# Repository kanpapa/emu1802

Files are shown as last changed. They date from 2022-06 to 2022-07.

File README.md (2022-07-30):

# emu1802
The computer with only COSMAC CDP1802 and PIC18F47Q43/PIC18F27Q43  
developed by Kazuhiro Ouchi

The purpose of this experiment is to see if it is possible to make a real COSMAC work with fewer components, at a lower cost, and more compactly.

The EMU1802 is replacement the CPU of the EMUZ80 with a COSMAC.  
The EMU1802-mini is replacement the PIC of the EMU1802 with a PIC18F27Q43.  

## Repository Contents
- [emu1802.X](/emu1802.X/) - PIC18F47Q43 ROM RAM and UART emulation firmware for EMU1802
- [emu1802mini.X](/emu1802mini.X/) - PIC18F27Q43 ROM RAM and UART emulation firmware for EMU1802-mini
- [production](/production/) - Firmware hex files for EMU1802-mini
- [idiotmon](/idiotmon/) - IDIOT/4 monitor and sample programs
- [kicad/emu1802_sch.pdf](/kicad/emu1802_sch.pdf) - schematic of EMU1802
- [kicad/emu1802_mini_sch.pdf](/kicad/emu1802_mini_sch.pdf) - schematic of EMU1802-mini
- [kicad/emu1802_mini_bom.md](/kicad/emu1802_mini_bom.md) - BOM of EMU1802-mini
- [test_programs](/test_programs/) - Test programs for EMU1802 hardware
- [tools/bin2hexsrc.py](/tools/bin2hexsrc.py) - A tool to convert binaries to HEX
- [EMU1802mini_Setup_ja.md](/EMU1802mini_Setup_ja.md) - Setup manual for EMU1802mini (Japanese)
- [README.md](/README.md) - This manual

## Development tools
- [Microchip MPLAB IDE v6.00](https://www.microchip.com/en-us/tools-resources/develop/mplab-x-ide)
- [Microchip MPLAB SNAP](https://www.microchip.com/en-us/development-tool/PG164100)
- [SB-Assembler 3](https://www.sbprojects.net/sbasm/)
- Python3

## Blog
You can also refer to my blog. (in Japanese)  
https://kanpapa.com/cosmac/blog/emu1802/

## Pictures

The EMU1802-mini  
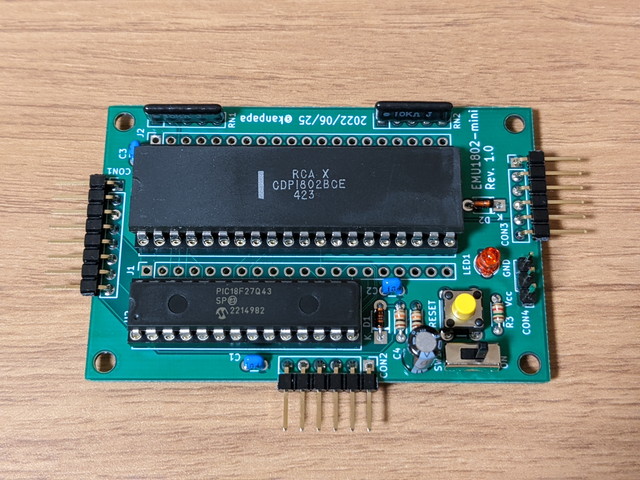
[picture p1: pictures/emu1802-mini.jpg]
EMU1802-mini


Testing of the EMU1802-mini  
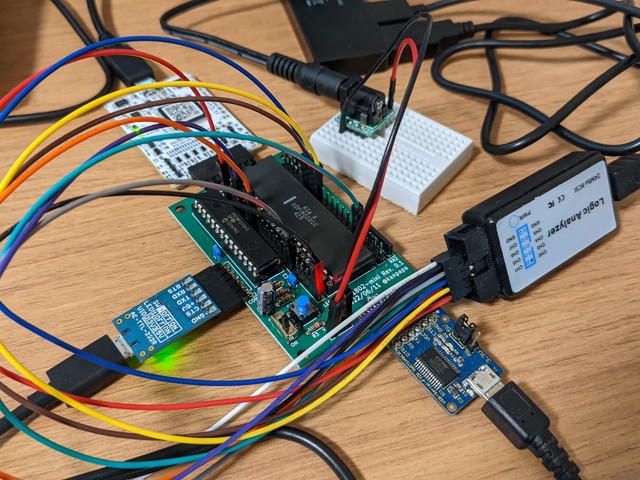
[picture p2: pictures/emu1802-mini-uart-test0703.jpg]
Testing of EMU1802-mini


The idiot monitor is working on the EMU1802-mini  
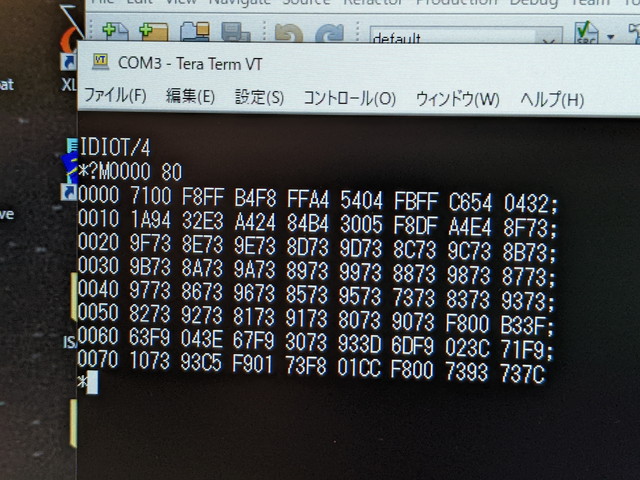
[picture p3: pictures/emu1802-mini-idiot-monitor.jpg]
The idiot monitor is working on emu1802-mini


Prototype of The EMU1802  
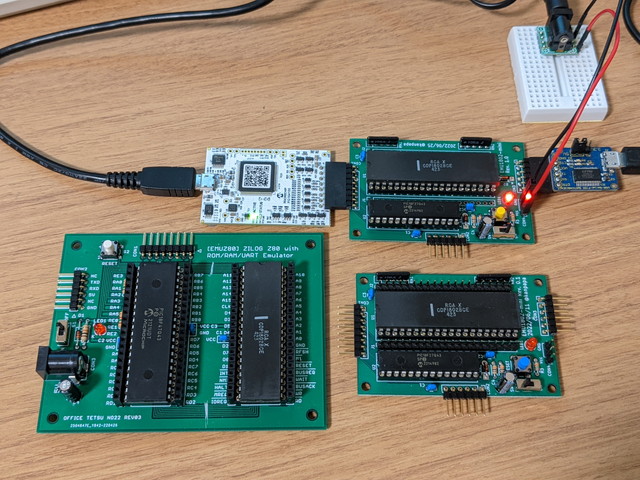
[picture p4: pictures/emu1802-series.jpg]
Prototype of The EMU1802


## License Information
References to any products, programs or services do not imply that they will be available in all countries in which their respective owner operates.  

Company, product, or services names may be trademarks or services marks of others.  

All libraries used in this code are copyright their respective authors.  

This project is based on the EMUZ80 hardware and software developed by Tetsuya Suzuki.

EMUZ80 - The computer with only Z80 and PIC18F47Q43  
  Written by Tetsuya Suzuki  
  https://github.com/vintagechips/emuz80  

The firmware includes the IDIOT monitor.  

IDIOT/4 MONITOR FOR THE 1802  
  WRITTEN: 6/23/82 BY LEE HART  
  COPYRIGHT 1982-85 BY TMSI  
  This program may be used for any noncommercial use free of charge.  
  fixes by Herb Johnson HRJ April 2010, Jan 2014  
  https://www.retrotechnology.com/memship/mship_idiot.html

Thanks to Gazelle for optimizing the firmware.  

  Modified by Gazelle  
  https://drive.google.com/drive/folders/14-OX5THzVz1BVxLPXheExVnpIBqS79NJ  
  1st release 2022-7-29

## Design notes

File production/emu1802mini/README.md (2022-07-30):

# production/emu1802mini
This is the firmware for the EMU1802-mini.  
It has been written to the PIC18F27Q43 with MPLAB X IPE v6.00 and MPLAB SNAP and confirmed to work.

## Repository Contents
There are two versions of the firmware.

- [v1_0](/production/emu1802mini/v1_0) : V1.0 - Original version of the IDIOT monitor, with ORG address changed to 0000H is included in the firmware. 300 bps is available.

- [v1_1](/production/emu1802mini/v1_1) : V1.1 - The IDIOT monitor that can use UART of PIC18F27Q43 is included in the firmware. 9600bps is available.

- [v2_1G](/production/emu1802mini/v2_1G) : V2.1G - Speedup to 1.79 MHz. Modified by Gazelle. 9600bps is available.

## License Information
This firmware includes the IDIOT monitor.
Please use it in compliance with the copyright and terms of use of the IDIOT Monitor.

IDIOT/4 MONITOR FOR THE 1802  
WRITTEN: 6/23/82 BY LEE HART  
COPYRIGHT 1982-85 BY TMSI  
This program may be used for any noncommercial use free of charge.  
fixes by Herb Johnson HRJ April 2010, Jan 2014  
https://www.retrotechnology.com/memship/mship_idiot.html

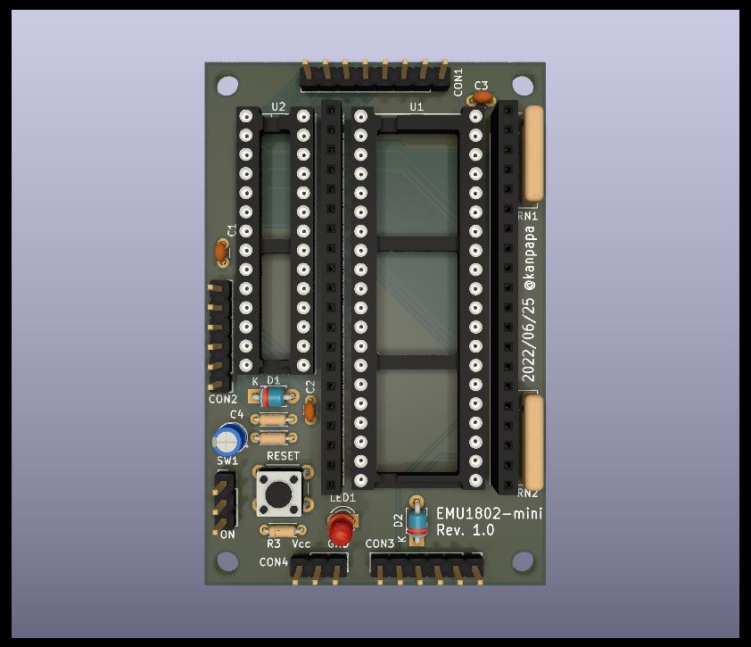
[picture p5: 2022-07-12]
pictures/emu1802_mini_front_3d.jpg

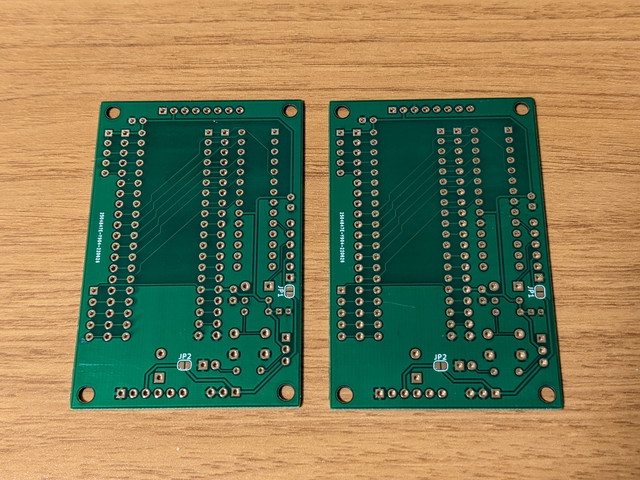
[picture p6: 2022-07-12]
pictures/emu1802-mini-pcb-back.jpg

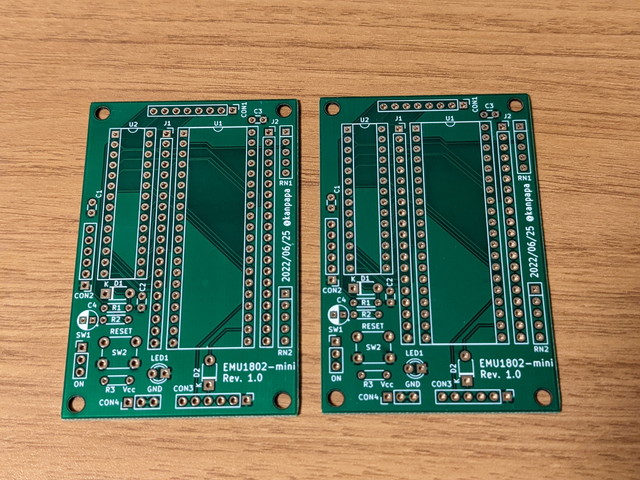
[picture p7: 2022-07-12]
pictures/emu1802-mini-pcb-front.jpg

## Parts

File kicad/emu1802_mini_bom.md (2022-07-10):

# EMU1802-mini Rev1.0 BOM
|Item|Qty|Reference(s)|Value|Description|Datasheet|
| --- | --- | --- | --- | --- | --- |
|1|3|C1, C2, C3|0.1u|Leaded MLCC 0.1uF50V 2.54mm|https://akizukidenshi.com/catalog/g/gP-00090/|
|2|1|C4|10uF|capacitor 10uF50V|https://akizukidenshi.com/catalog/g/gP-03116/|
|3|1|CON1|PICKIT/SNAP|2.54mm 8-Pin header strip straight(or right angle) single row|https://akizukidenshi.com/catalog/g/gC-00167/|
|4|1|CON2|UART|2.54mm 6-Pin header strip straight(or right angle) single row|https://akizukidenshi.com/catalog/g/gC-00167/|
|5|1|CON3|Software Serial|2.54mm 6-Pin header strip straight(or right angle) single row|https://akizukidenshi.com/catalog/g/gC-00167/|
|6|1|CON4|DC-IN|2.54mm 3-Pin header strip straight(or right angle) single row|https://akizukidenshi.com/catalog/g/gC-00167/|
|7|2|D1, D2|1N4148| Small Signal Diode 1N4148|https://akizukidenshi.com/catalog/g/gI-00941/|
|8|2|J1, J2|CPUA/B|2.54mm 20-Pin female header single row straight dip|https://akizukidenshi.com/catalog/g/gC-03077/|
|9|1|LED1|POWER LED|3mm LED|https://akizukidenshi.com/catalog/g/gI-11577/|
|10|2|R1, R2|10k|resistor 10k 1/6W|https://akizukidenshi.com/catalog/g/gR-16103/|
|11|1|R3|1.5k|resistor 1.5k 1/6W|https://akizukidenshi.com/catalog/g/gR-16152/|
|12|2|RN1,RN2|10K|SIP resistor 5-pin 4 x 10k|https://akizukidenshi.com/catalog/g/gR-11909/|
|13|1|SW1|POWER|slide switch SS-12D00G3|https://akizukidenshi.com/catalog/g/gP-15707/|
|14|1|SW2|RESET|tact switch TS-0606|https://akizukidenshi.com/catalog/g/gP-03649/|
|15|1|U1|CDP1802ACE|CDP1802ACE microprocessor|http://www.cosmacelf.com/publications/data-sheets/cdp1802.pdf|
|16|1|U2|PIC18F27Q43|Microchip PIC18F27Q43 microprocessor|https://akizukidenshi.com/catalog/g/gI-16593/|
|17|1|U1 socket||40-Pin IC socket 600mil |https://akizukidenshi.com/catalog/g/gP-00034/|
|18|1|U2 socket||28-Pin IC socket 300mil|https://akizukidenshi.com/catalog/g/gP-01339/|

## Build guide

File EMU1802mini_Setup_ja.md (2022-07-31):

# EMU1802-mini セットアップマニュアル

## EMU1802-miniとは

EMU1802-miniはCOSMAC CDP1802 CPUとPIC18F27Q43だけで動作するシングルボードコンピュータです。
PIC18F27Q43とPICに書き込むファームウェアで周辺デバイスであるROM, RAM, UARTの機能を実現しています。
Tetsuya Suzuki氏が開発した[EMUZ80](https://vintagechips.wordpress.com/2022/03/05/emuz80_reference/)を参考にして製作しています。  
COSMAC CPUについては[COSMAC研究会](https://kanpapa.com/cosmac/cosmac-cpu.html)のサイトをご覧ください。
これまでの経緯をまとめた[EMU1802アーカイブ](https://kanpapa.com/cosmac/blog/emu1802/)もあります。

EMU1802-miniの完成写真  
EMU1802-mini

## ハードウェアの製作

1. [回路図](/kicad/emu1802_mini_sch.pdf)と[BOM](/kicad/emu1802_mini_bom.md)を参考にしてパーツを入手してください。
1. [EMU1802-mini専用プリント基板](https://store.shopping.yahoo.co.jp/orangepicoshop/pico-A-057.html)があればパーツを基板に実装してハンダ付けします。基板がない場合はブレッドボードを使って配線しても良いでしょう。

- [EMU1802-mini専用プリント基板](https://store.shopping.yahoo.co.jp/orangepicoshop/pico-A-057.html)について

  - [オレンジピコショップ](https://store.shopping.yahoo.co.jp/orangepicoshop/)さんで購入できます。
  - EMU1802-mini専用基板を使用する際の注意事項
    - 基板には最低限の情報しかシルク印刷されていません。作業開始前に回路図を確認することをお勧めします。
    - CON4は電源入力です。１番ピンがVccです。２番ピンと３番ピンはGNDです。誤ってショートしないように注意してください。
    - CON2, CON3はUSBシリアルを接続するコネクタです。１番ピンがGNDになります。
    - USBシリアルから電源を供給する場合は裏面のJP1またはJP2を半田でショートしてください。
    - 省スペースのために1/6W抵抗を使用していますが、1/4W抵抗の場合はリード線を曲げて縦に取り付けてください。

## 開発環境の準備

- [Microchip MPLAB X IDE v6.00](https://www.microchip.com/en-us/tools-resources/develop/mplab-x-ide)が必要です。  
- ファームウェアの書き込みには[Microchip MPLAB SNAP](https://akizukidenshi.com/catalog/g/gM-13854)を使用します。
- ファームウェアのROM領域を変更する場合は[SB-Assembler 3](https://www.sbprojects.net/sbasm/)を使用します。このアセンブラはPython3で書かれているため、LinuxやMacやWindowsでPython3が動けば動作します。私の場合はWSL2環境にインストールしています。  

## ファームウェアのビルドと書き込み手順

EMU1802-miniはCOSMACのプログラムをPICのファームウェアに組み込んで使います。好きなプログラムを動かすためにはファームウェアのビルドは必須です。

1. [emu1802mini.X](/emu1802.X)を適当な場所に展開します。
1. [Microchip MPLAB X IDE v6.00](https://www.microchip.com/en-us/tools-resources/develop/mplab-x-ide)を起動します。
1. プロジェクトを開くで展開したemu1802mini.Xフォルダを指定して開きます。
1. MPLAB IDEでビルドを行いコンパイルができることを確認します。
1. EMU1802-miniのCON1にMPLAB SNAPを接続し、PCのUSBに接続します。
1. EMU1802-miniの電源を投入します。
1. MPLAB IDEでターゲットのPICに書き込みを行います。

## ビルド済みファームウェアの書き込み手順

[production](/production)にIDIOTモニタが含まれたビルド済のファームウェアのHEXファイルがありますので、これを利用することもできます。

1. 使用したいファームウェアをダウンロードしてください。詳しくは[README.md](/production/emu1802mini/README.md)を参照してください。
1. EMU1802-miniのCON1にMPLAB SNAPを接続し、PCのUSBに接続します。
1. EMU1802-miniの電源を投入します。
1. MPLAB IPEを起動します。
1. Device and Tool Selectionで、DeviceでPIC18F27Q43を選択し、ToolはSNAPを選択してください。
1. Hex FileのBrowseボタンを押して、ダウンロードしたファームウェアのHEXファイルを指定してください。
1. Erase→Blank Check→Program→Verifyを順に実行し、ターゲットのPICに書き込みます。

## EMU1802-miniの動作確認

ファームウェアV1.0の場合

1. USBシリアルをCON3（COSMACのQ/EF3）に接続します。
1. USBシリアルにPCを接続し、ターミナルプログラム(TeraTermなど）で300bps、スタート1ビット、データ長7ビット、パリティMark、ストップ1ビットに設定します。
1. EMU1802-miniの電源を投入します。
1. Enterキーを押すと、「IDIOT/4」起動メッセージとプロンプトの「*」が表示されます。

ファームウェアV1.1/V2.1Gの場合

1. USBシリアルをCON2（PICのUART）に接続します。
1. USBシリアルにPCを接続し、ターミナルプログラム(TeraTermなど）で9600bps、スタート1ビット、データ長8ビット、パリティ無し、ストップ1ビットに設定します。
1. EMU1802-miniの電源を投入します。
1. 「IDIOT/4」起動メッセージとプロンプトの「*」が表示されます。

## IDIOTモニタの使い方

### 基本的なコマンド

指定する値は16進数です。

| コマンド | 機能 |
----|----
|?Maaaa xx|アドレスaaaaからxxバイト分のメモリをダンプします |
|!Maaaa dd..dd;|アドレスaaaaから、ddの内容を書き込みます。<br>セミコロンをつけると次の行の内容も継続して書き込まれます。<br>これにより?Mコマンドでダンプした内容をキャプチャしておけば、キャプチャした内容をそのまま復元できます。|
|$Paaaa|割り込みを有効にして、PレジスタとXレジスタを0に設定した状態で、aaaaアドレスからのプログラムを実行します。|
|?R|最後の割り込み後に保存されたCPUのレジスタの値を表示します。|
|$Rxp|8FB8-8FDFのRAM領域の情報をCPUレジスタに設定します。<br>その後コマンドパラメタのxをXレジスタに、pをPレジスタに設定してプログラムの実行を行います。<br>つまり、Pレジスタで指定されたレジスタの内容が実行開始アドレスとなります。|

?Rコマンドの表示例

```
*?R
8FB8 00B2 0000 0000 0000;
8FC0 8000 00BB 8FE2 014E 0202 0224 FA7B 6BAD;
8FD0 002C BFFF 8004 5D6D 00EF 0000 0201 8080
```

レジスタとの対応は以下の通りです。

```
8FB8 ID T  DF D  IE Q  EF1234
8FC0 R0 R1 R2 R3 R4 R5 R6 R7
8FD0 R8 R9 RA RB RC RD RE RF
```

このレジスタの内容を使って$Rコマンドでレジスタの状態を設定したあとに実行することができます。

### コマンドの使用例

エコーバックをするプログラムを書き込んで実行した操作例です。  
ターミナルからテキストをアップロードする時は適切な送信遅延を入れてください。（後述の制限事項の項目を参照）

```
IDIOT/4
*!M8000 F880B4B5F817A4F80BA5D5F801B3F83EA3D354F89CA3D3003007
*?M8000 20
8000 F880 B4B5 F817 A4F8 0BA5 D5F8 01B3 F83E;
8010 A3D3 54F8 9CA3 D300 3007 0000 0000 0000
*$P8000
```

他にも有用なコマンドがあるかもしれません。詳細はソースファイルまたはIDIOTモニタのサイトを参照してください。  

- [COSMAC 1802 "IDIOT" monitor Software](https://www.retrotechnology.com/memship/mship_idiot.html)

## ファームウェアのカスタマイズ方法

### メモリマップの変更

main.cの以下の部分で設定できます。現在はROMエリアは$0000-$03FF、RAMエリアは$8000-8FFFとしています。ROMエリアは16Kbyte（$0000～$3FFF）まで設定できます。

```
#define ROM_SIZE 0x0400 // ROM size 1k bytes
#define RAM_SIZE 0x1000 // RAM size 4k bytes
#define RAM_TOP 0x8000 // RAM start address
```

### CPUクロックの変更

main.cの以下の部分の値を変更します。V2.1Gでは1.79MHzになっています。これ以上速くするとタイミングが合わなくなり動かなくなります。

```
#define Z80_CLK   1790000UL // CDP1802 clock frequency(2MHz)
```

### ROM領域の変更

ファームウェアのROM領域を変更する場合は[SB-Assemblers](https://www.sbprojects.net/sbasm/)でアセンブルしてバイナリファイルを生成したあとに、ファームウェアのソースファイルに組み込むためのHEXデータに変換します。  
[SB-Assemblers](https://www.sbprojects.net/sbasm/)のインストールと使用方法は公式サイトでご確認ください。  
インストールがうまくできていれば、以下のようにソースファイル名を指定するだけでカレントディレクトリにバイナリファイルとリストファイルができます。  

```
sbasm idiot_0000.asm
```

生成されたバイナリファイルを16進データ形式に変換するPythonプログラム [tools/bin2hexsrc.py](tools/bin2hexsrc.py) を用意していますので、これを使うとソースに組み込むデータを簡単に作成できます。  
使い方は以下の通りです。

```
python3 bin2hexsrc.py idiot_0000.bin > idiot_0000.hexsrc
```

生成された16進データを以下のrom配列の部分に組み込んでください。  
組み込むデータがROM_SIZEを超えてしまう場合はメモリマップを調整してください。

```
const unsigned char rom[ROM_SIZE] = {
   :
}
```

## 制限事項

EMU1802-miniはCOSMAC CPUの周辺デバイスをPICに置き換えています。このため以下の制限事項があります。

- 通常のRAMにくらべてPICからの読み込みは遅く、CPUクロックに上限があります。現在は1.79MHzが上限です。
- RESETを押すとRAM領域が初期化されます。通常のRAMですと電源が入っていればメモリの状態が保持されますが、PICがリセットされるのでRAMエリアは初期化されます。このため後述するIDIOTモニタの割り込みを活用してください。
- CPUの処理速度がついていけず、ターミナルからの入力で文字を取りこぼす場合があります。特にテキストをアップロードする時は適切な送信遅延を入れてください。目安として20ミリ秒/字、500ミリ秒/行程度は必要です。

## EMU1802-miniでのCOSMAC CPUの楽しみ方

### BASICを動かす方法

Lee A. Hart.さんの[The 1802 Membership Card](http://www.sunrise-ev.com/1802.htm)用のMCBASIC3が動きます。  

[The 1802 Membership Card](http://www.sunrise-ev.com/1802.htm)のページにある[MCBASIC3.bin](http://www.sunrise-ev.com/MembershipCard/MCBASIC3.bin)を使用してください。  
バイナリのサイズは16Kbyteですので、ソースのROMサイズを以下のように変更してください。  

```
#define ROM_SIZE 0x4000 // ROM size 16k bytes
```

あとは、ダウンロードしたMCBASIC3.binをbin2hexsrc.pyでソースに組み込むデータを作成して、ROM領域に組み込んでください。  
これはソフトウェアシリアルを使用しますので、USBシリアルをCON3に接続してください。シリアル速度の設定は以下の通りです。  

- Speed 9600bps
- Data 8bit
- Parity none
- Stop 1bit

正常に起動すると以下のように表示されます。

```
WELCOME TO THE 1802 BASIC3 V1.1
(C)1981 RCA
C/W?
```

C/W?とありますが、CはCOLD START、WはWARM START(*1)です。  
Cを入力するとREADYと表示され、入力待ちを表すコロン(:)が表示されます。この状態でBASICプログラムが入力できます。  
詳しい使い方はThe 1802 Membership CardのサイトにBASIC3 User Manualがありますのでそちらを参照ください。  
なお、少し速くタイピングしたり、ターミナルプログラムからファイルをアップロードしようとすると入力文字を取りこぼしますので適度な送信遅延をいれてください。  

*1 EMU1802-miniではリセット後にRAM領域がクリアされてしまうため、WARM STARTは利用できません。常にCOLD STARTで起動してください。

### PICのUARTにアクセスする方法

$E000, $E001がPICのUARTレジスタのアドレスになります。使用例は[サンプルプログラム](/test_programs/uart_echo/)で確認してください。

### ファームウェアV2.1Gについて

ファームウェアV2.1GはGazelle氏により大幅に高速化が図られたものです。ソースコードの開発および公開に感謝いたします。  
V1.x系とは処理方式が大きく変更されています。これまではTPBの立ち上がりでメモリーを読んでいましたが、V2.1Gでは割り込みを使わずにポーリングを使ってTPAの立下り直後のCLOCK立ち上がりで
アドレスを確定しています。さらにコンパイラの最適化レベルを2にしています。  
これによりCPUクロックの高速化が実現し、ソフトウェアシリアルでも9600bpsに対応できるようになりました。ソフトウェアシリアルを使用している膨大な1802の資産が動かせそうです。  
V2.1Gに標準で組み込まれているIDIOTモニタはPIC内蔵のUART対応版ですが、ROM領域の#ifdef ～　#endif の場所を変更することでソフトウェアシリアル版のIDIOTモニタに切り替えることができます。  
暫定的なコーディングとなっていますが、これまでテストに使ったプログラムも残っているので参考にしてください。

### IDIOTモニタの割り込みを活用する

IDIOTモニタではハードウェア割り込みとソフトウェア割り込みをサポートしています。

- ハードウェア割り込み  
   CPUのINTERRUPTピンをLOWにすると、IDIOTモニタの割り込みハンドラに制御が渡りTレジスタを除く全レジスタがRAM領域に保存され、IDIOTのコマンド入力待ちになります。
- ソフトウェア割り込み  
   SEP R1命令（バイナリではD1）を実行すると、ハードウェア割り込みと同様の動きをします。PレジスタとXレジスタを除く全てのレジスタがRAM領域に保存され、IDIOTのコマンド入力待ちになります。
- レジスタ情報の確認  
   割り込み発生後にIDIOTモニタで?Rコマンドを入力してRAM領域に保存されたレジスタの状態を確認できます。
- 割り込みで中断したプログラムの再開  
   $Rコマンドを入力することで、RAM領域に保存されている情報がレジスタに書き戻され、中断したプログラムを再開することもできます。再開前にRAM領域を書き換えることで各レジスタを任意の値に設定してプログラムを再開することもできます。  

このようにプログラムのデバックやCOSMAC CPUの学習に活用できます。

## 参考ブログ

- <https://kanpapa.com/cosmac/blog/emu1802/>

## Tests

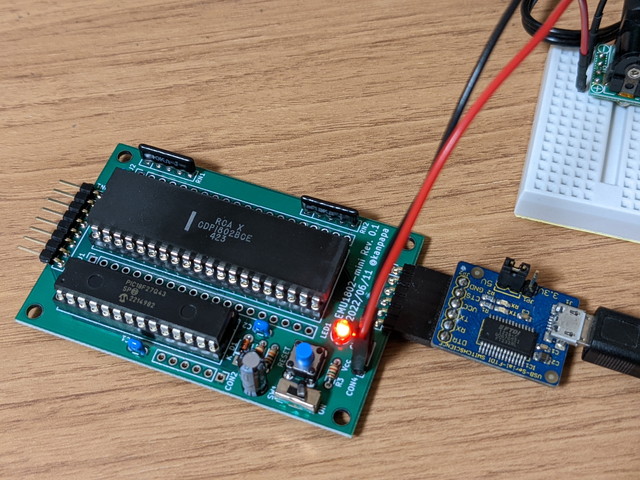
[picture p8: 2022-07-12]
pictures/emu1802_clockup_testing1.jpg

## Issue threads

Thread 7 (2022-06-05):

Use the PIC's UART.

kanpapa, 2022-06-05:
Increase the serial communication speed of the IDIOT monitor with a UART on the PIC.

kanpapa, 2022-07-04:
Fixed #36

kanpapa, 2022-07-09:
Released #41

Closed 2022-07-09.

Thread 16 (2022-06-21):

I need a diode at the serial input to prevent reverse current.

kanpapa, 2022-06-21:
It looks like I should put a diode at the serial input of EF3 to prevent reverse current.
I will revise this if I have to revise next time.

kanpapa, 2022-07-02:
Schematic has been corrected. #30 #31

kanpapa, 2022-07-13:
Fixed #48

Closed 2022-07-13.

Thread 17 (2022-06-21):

Using the power supply of the USB serial board

kanpapa, 2022-06-21:
I would like to add a jumper for connection so that I can use the power output of the USB serial board.

kanpapa, 2022-07-05:
We will correct this on the next PCB.

kanpapa, 2022-07-13:
Fixed #48

Closed 2022-07-13.

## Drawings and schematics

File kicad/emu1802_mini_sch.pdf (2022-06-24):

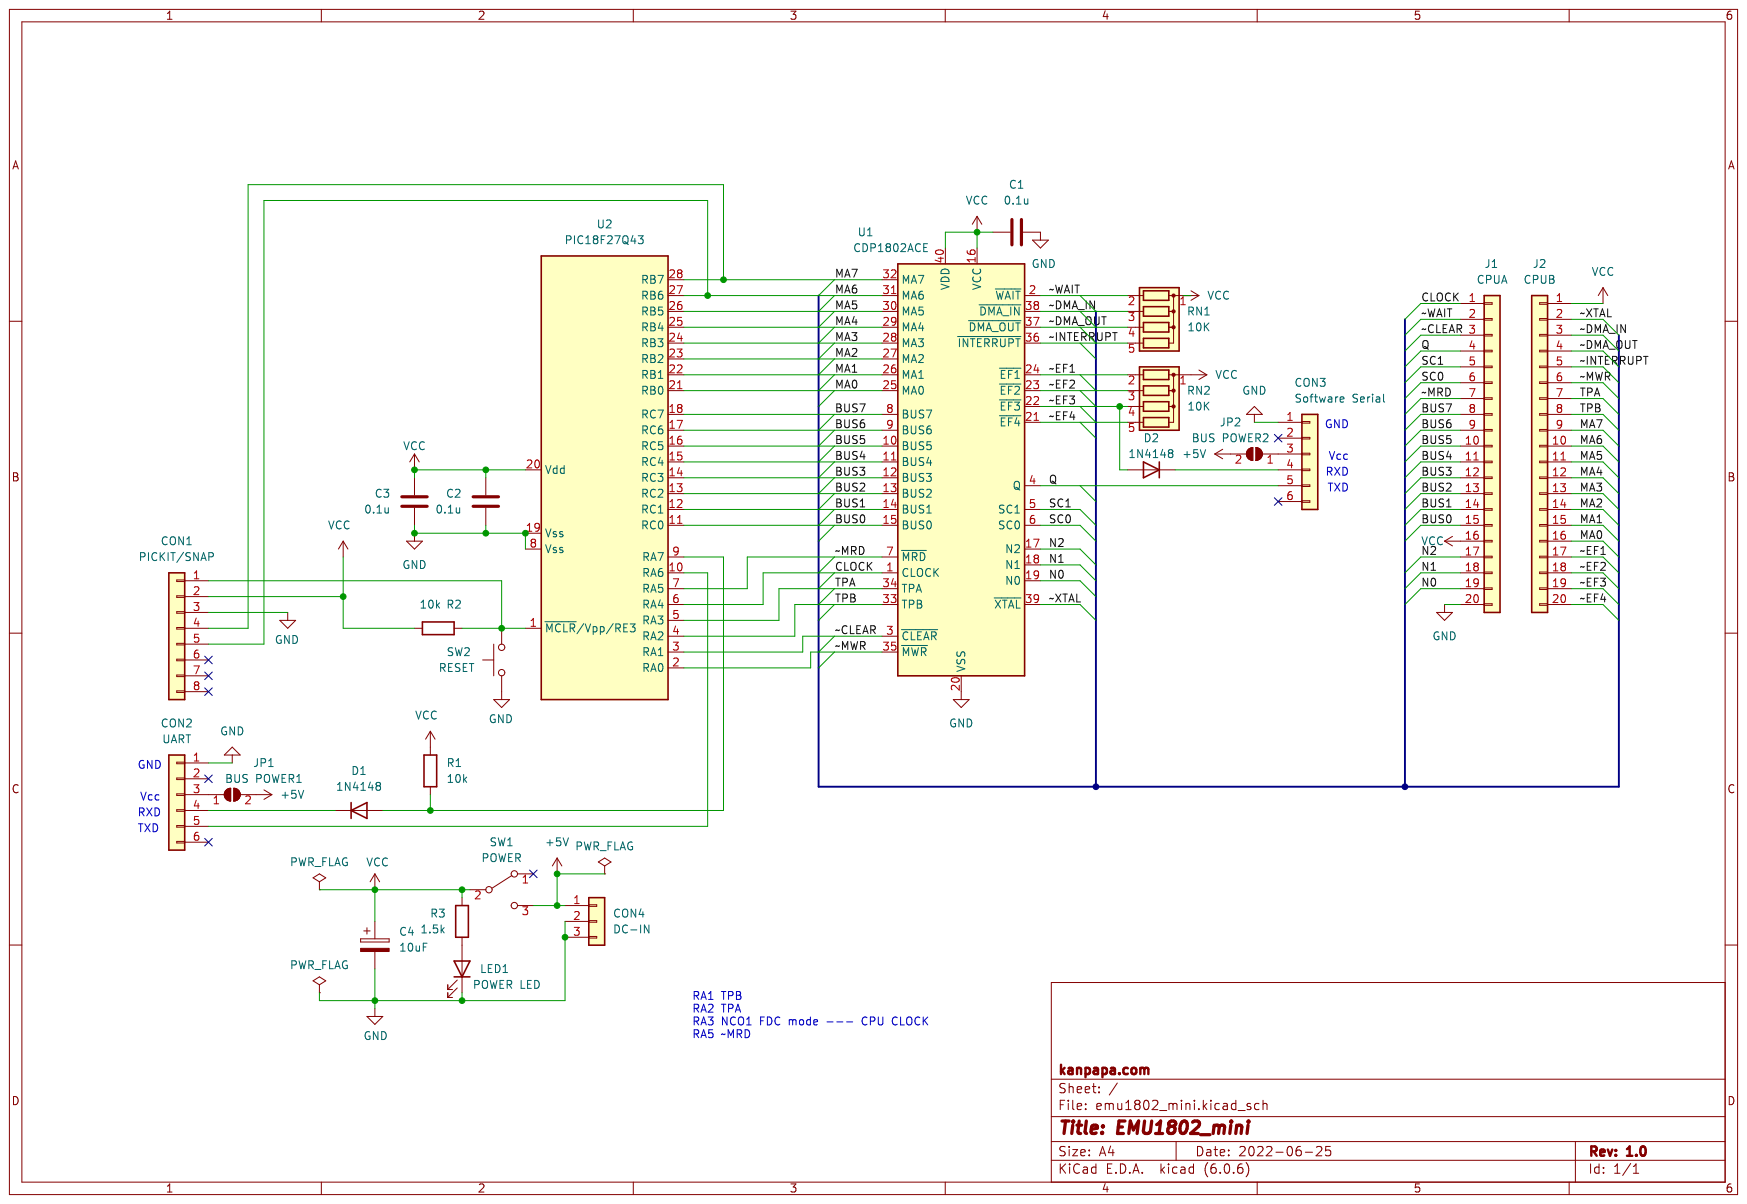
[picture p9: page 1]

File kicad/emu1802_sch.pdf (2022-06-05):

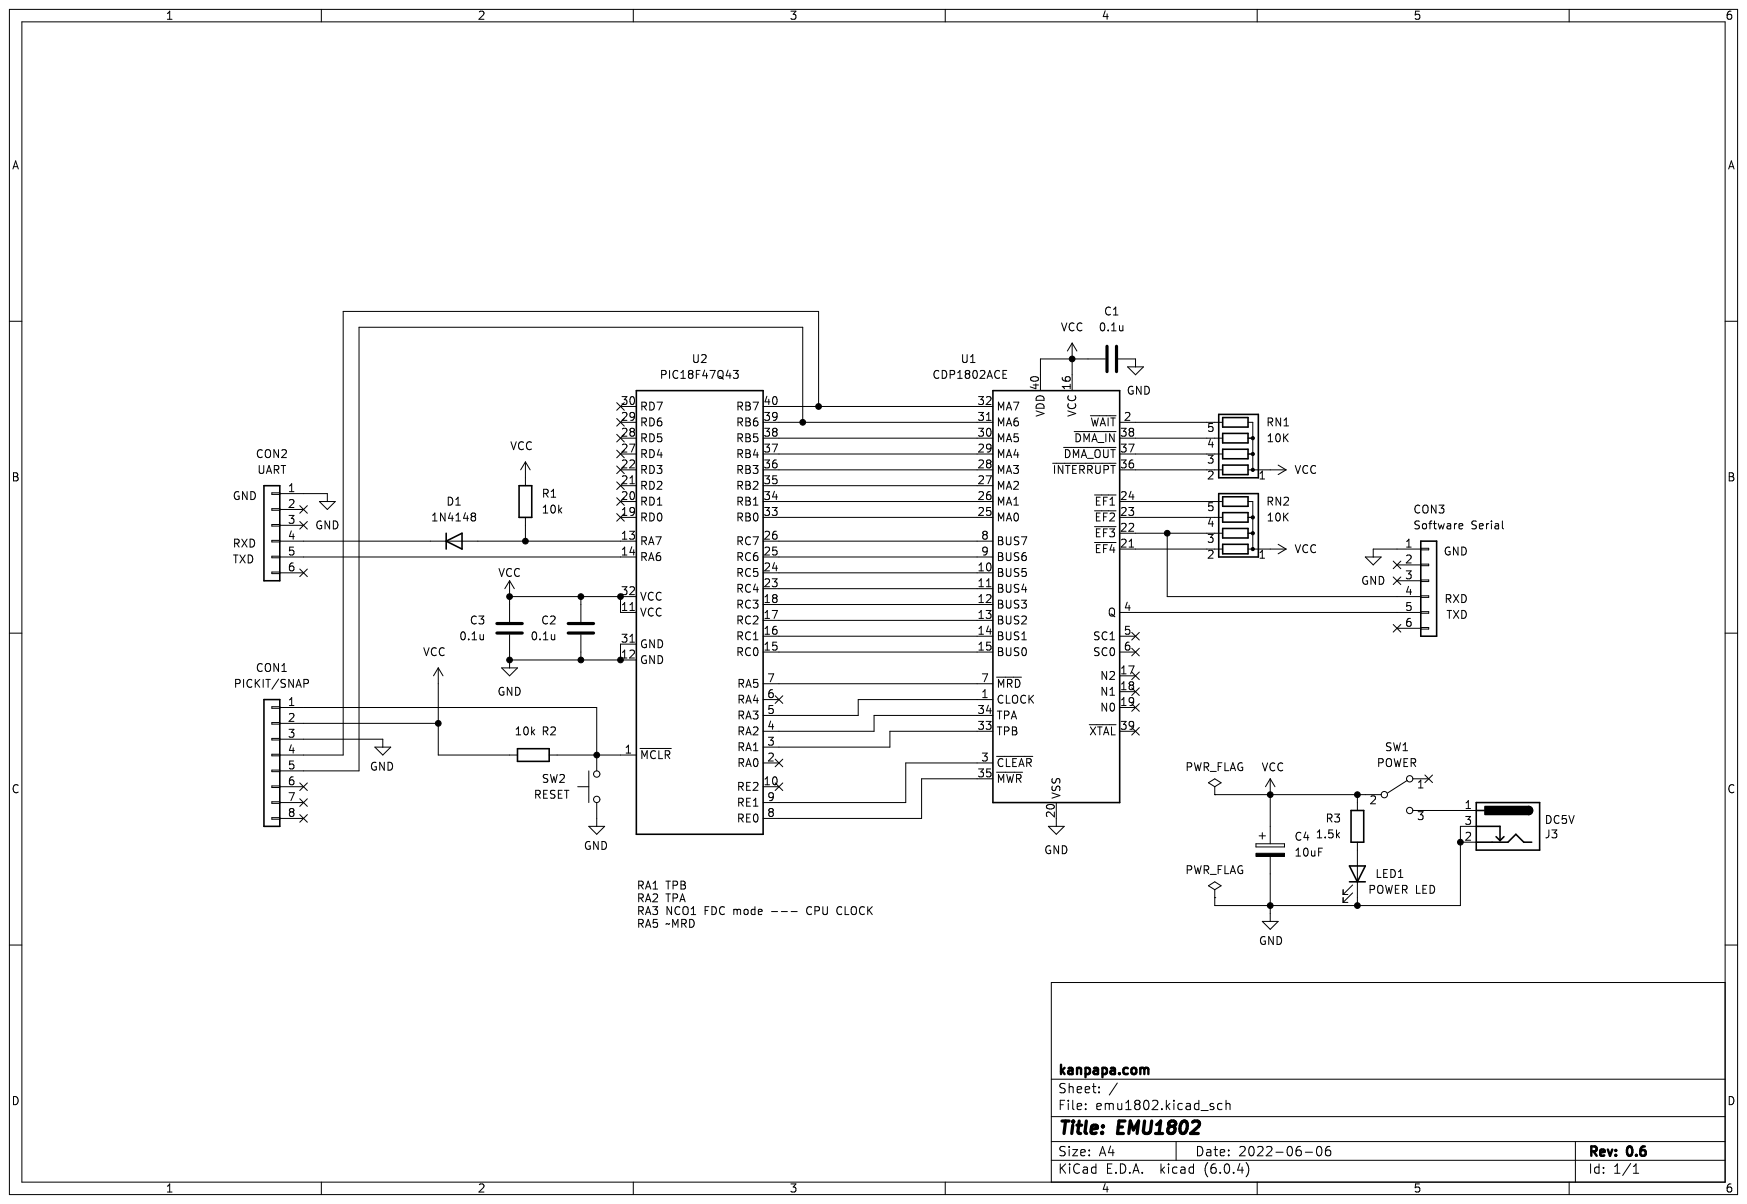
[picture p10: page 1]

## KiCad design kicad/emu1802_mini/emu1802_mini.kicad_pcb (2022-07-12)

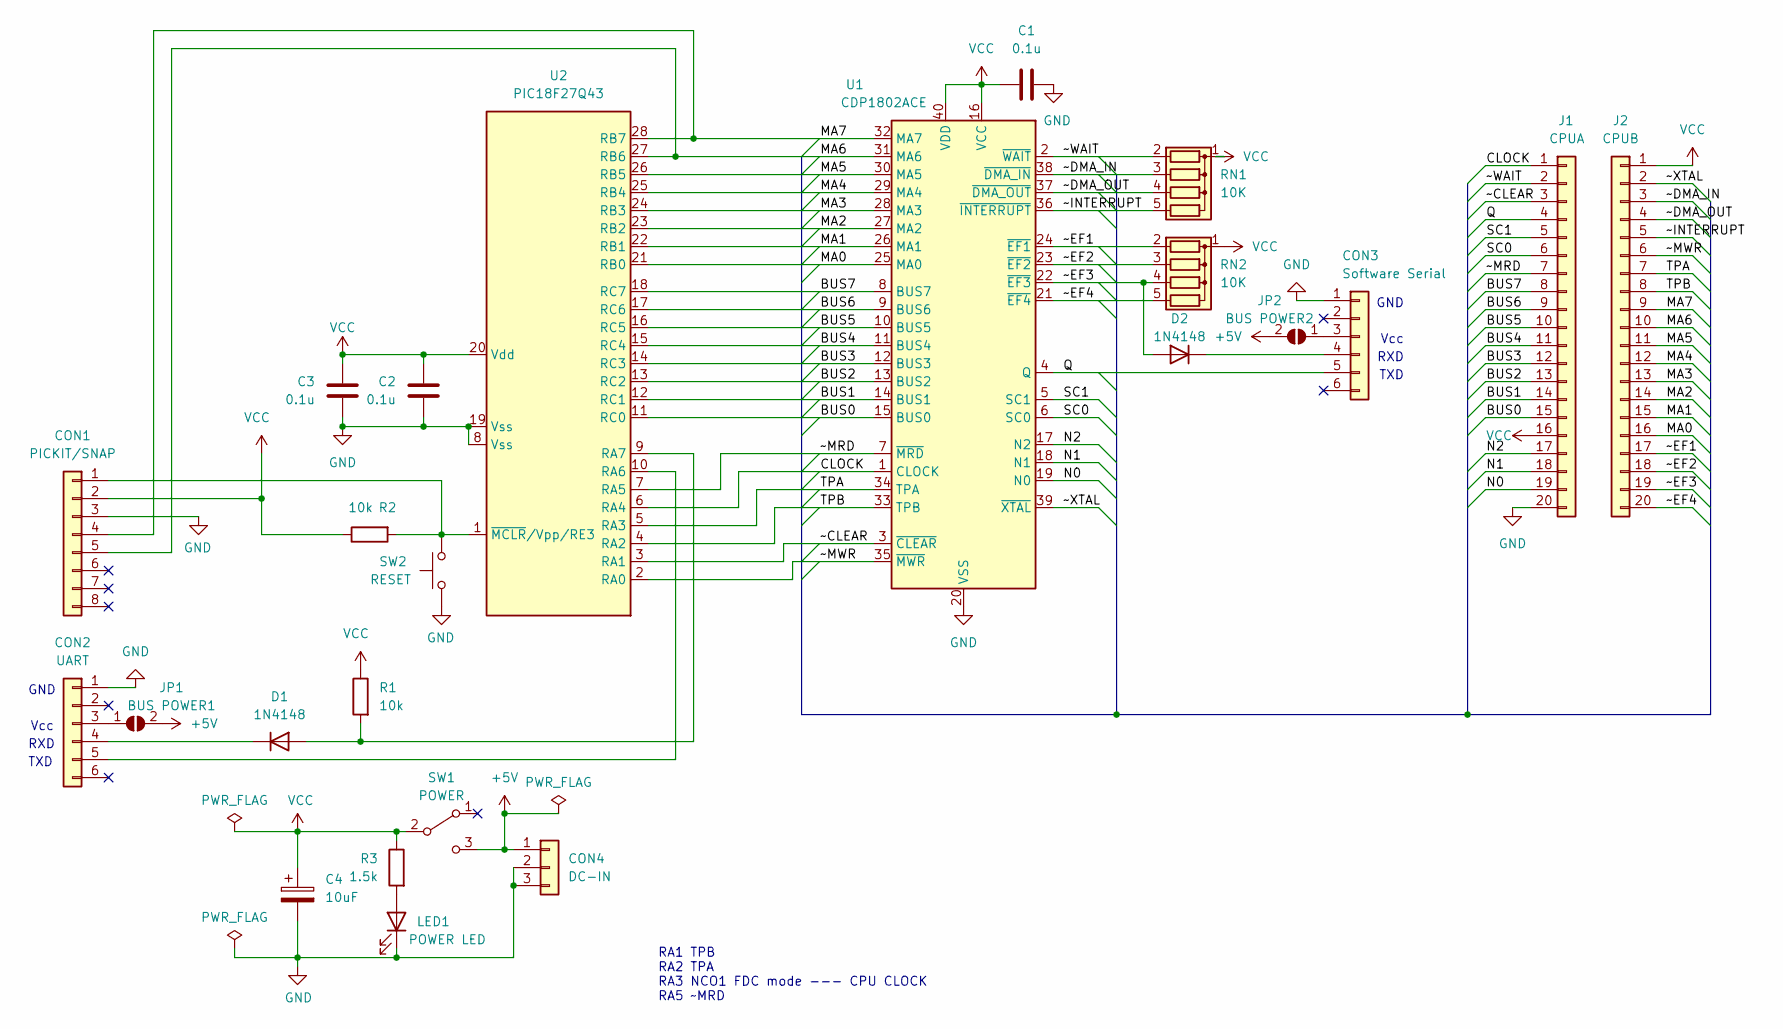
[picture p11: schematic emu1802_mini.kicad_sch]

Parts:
C1, C2, C3: 0.1u; C_Disc_D3.0mm_W1.6mm_P2.50mm
C4: 10uF; CP_Radial_D4.0mm_P2.00mm
CON1: PICKIT/SNAP; PinHeader_1x08_P2.54mm_Vertical
CON2: UART; PinHeader_1x06_P2.54mm_Vertical
CON3: Software Serial; PinHeader_1x06_P2.54mm_Vertical
CON4: DC-IN; PinHeader_1x03_P2.54mm_Vertical
D1, D2: 1N4148; D_T-1_P5.08mm_Horizontal
J1: CPUA; PinSocket_1x20_P2.54mm_Vertical
J2: CPUB; PinSocket_1x20_P2.54mm_Vertical
JP1: BUS POWER1; SolderJumper-2_P1.3mm_Open_RoundedPad1.0x1.5mm
JP2: BUS POWER2; SolderJumper-2_P1.3mm_Open_RoundedPad1.0x1.5mm
LED1: POWER LED; LED_D3.0mm
R1, R2: 10k; R_Axial_DIN0204_L3.6mm_D1.6mm_P5.08mm_Horizontal
R3: 1.5k; R_Axial_DIN0204_L3.6mm_D1.6mm_P5.08mm_Horizontal
RN1, RN2: 10K; R_Array_SIP5
SW1: POWER; PinHeader_1x03_P2.54mm_Vertical
SW2: RESET; SW_PUSH_6mm
U1: CDP1802ACE; DIP-40_W15.24mm_Socket
U2: PIC18F27Q43; DIP-28_W7.62mm_Socket

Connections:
+5V: CON4.1, JP1.2 (B), JP2.2 (B), SW1.3 (C)
/BUS0: J1.15, U1.15 (BUS0), U2.11 (RC0)
/BUS1: J1.14, U1.14 (BUS1), U2.12 (RC1)
/BUS2: J1.13, U1.13 (BUS2), U2.13 (RC2)
/BUS3: J1.12, U1.12 (BUS3), U2.14 (RC3)
/BUS4: J1.11, U1.11 (BUS4), U2.15 (RC4)
/BUS5: J1.10, U1.10 (BUS5), U2.16 (RC5)
/BUS6: J1.9, U1.9 (BUS6), U2.17 (RC6)
/BUS7: J1.8, U1.8 (BUS7), U2.18 (RC7)
/CLOCK: J1.1, U1.1 (CLOCK), U2.6 (RA4)
/MA0: J2.16, U1.25 (MA0), U2.21 (RB0)
/MA1: J2.15, U1.26 (MA1), U2.22 (RB1)
/MA2: J2.14, U1.27 (MA2), U2.23 (RB2)
/MA3: J2.13, U1.28 (MA3), U2.24 (RB3)
/MA4: J2.12, U1.29 (MA4), U2.25 (RB4)
/MA5: J2.11, U1.30 (MA5), U2.26 (RB5)
/MA6: CON1.5, J2.10, U1.31 (MA6), U2.27 (RB6)
/MA7: CON1.4, J2.9, U1.32 (MA7), U2.28 (RB7)
/N0: J1.19, U1.19 (N0)
/N1: J1.18, U1.18 (N1)
/N2: J1.17, U1.17 (N2)
/Q: CON3.5, J1.4, U1.4 (Q)
/SC0: J1.6, U1.6 (SC0)
/SC1: J1.5, U1.5 (SC1)
/TPA: J2.7, U1.34 (TPA), U2.5 (RA3)
/TPB: J2.8, U1.33 (TPB), U2.4 (RA2)
/~CLEAR: J1.3, U1.3 (~CLEAR), U2.3 (RA1)
/~DMA_IN: J2.3, RN1.3 (R2), U1.38 (~DMA_IN)
/~DMA_OUT: J2.4, RN1.4 (R3), U1.37 (~DMA_OUT)
/~EF1: J2.17, RN2.2 (R1), U1.24 (~EF1)
/~EF2: J2.18, RN2.3 (R2), U1.23 (~EF2)
/~EF3: D2.2 (A), J2.19, RN2.4 (R3), U1.22 (~EF3)
/~EF4: J2.20, RN2.5 (R4), U1.21 (~EF4)
/~INTERRUPT: J2.5, RN1.5 (R4), U1.36 (~INTERRUPT)
/~MRD: J1.7, U1.7 (~MRD), U2.7 (RA5)
/~MWR: J2.6, U1.35 (~MWR), U2.2 (RA0)
/~WAIT: J1.2, RN1.2 (R1), U1.2 (~WAIT)
/~XTAL: J2.2, U1.39 (~XTAL)
GND: C1.1, C2.2, C3.2, C4.2, CON1.3, CON2.1, CON3.1, CON4.2, CON4.3, J1.20, LED1.1 (K), SW2.2, U1.20 (VSS), U2.8 (Vss), U2.19 (Vss)
unnamed: CON1.1, R2.2, SW2.1, U2.1 (~MCLR/Vpp/RE3)
unnamed: CON2.3, JP1.1 (A)
unnamed: CON2.4, D1.1 (K)
unnamed: CON2.5, U2.10 (RA6)
unnamed: CON3.3, JP2.1 (A)
unnamed: CON3.4, D2.1 (K)
unnamed: D1.2 (A), R1.2, U2.9 (RA7)
unnamed: LED1.2 (A), R3.2
VCC: C1.2, C2.1, C3.1, C4.1, CON1.2, J1.16, J2.1, R1.1, R2.1, R3.1, RN1.1 (common), RN2.1 (common), SW1.2 (B), U1.16 (VCC), U1.40 (VDD), U2.20 (Vdd)

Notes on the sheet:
RXD
TXD
GND
Vcc
RA1 TPB RA2 TPA RA3 NCO1 FDC mode --- CPU CLOCK RA5 ~MRD

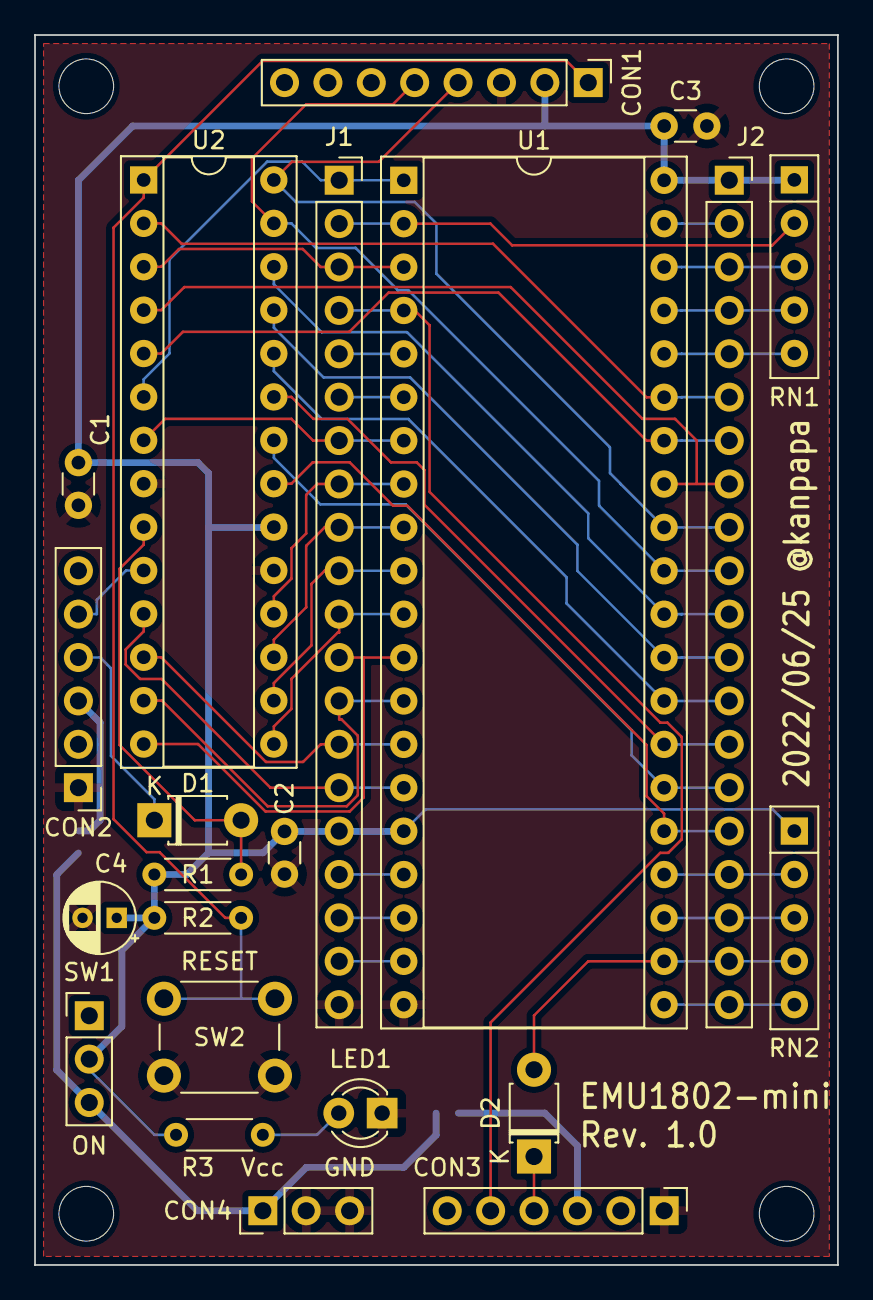
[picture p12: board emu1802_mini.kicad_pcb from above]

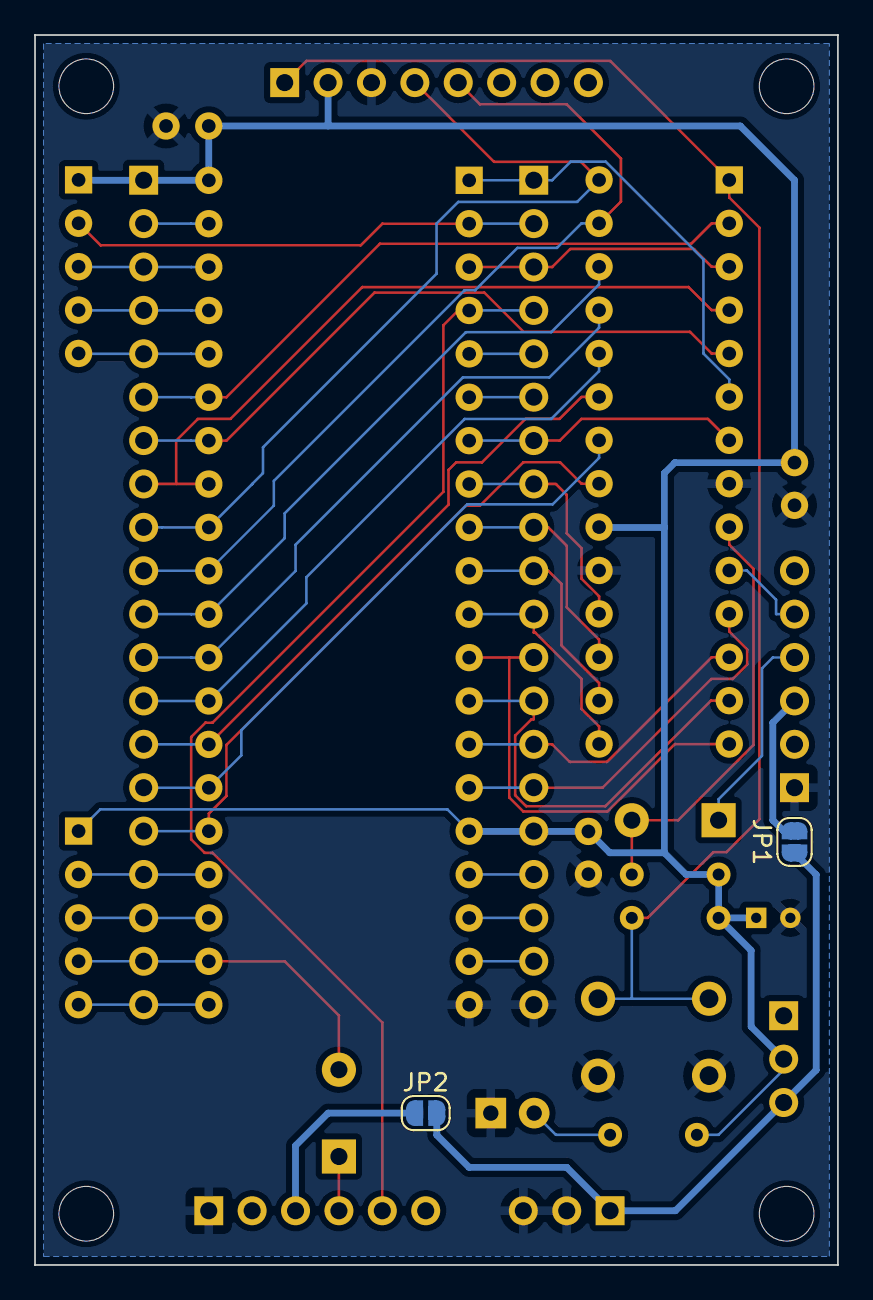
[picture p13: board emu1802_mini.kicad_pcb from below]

Board: 2 copper layers, 47.0 x 72.0 mm, 28 parts (2 on the bottom side), 48 nets.

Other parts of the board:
MH1, MH2, MH3, MH4: MountingHole_3.2mm_M3

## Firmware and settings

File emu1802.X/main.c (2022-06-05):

/*
  PIC18F47Q43 ROM RAM and UART emulation firmware
  This single source file contains all code

  Target: EMUZ80 - The computer with only Z80 and PIC18F47Q43
  Compiler: MPLAB XC8 v2.36
  Written by Tetsuya Suzuki

  Target: EMU1802 - The computer with only COSMAC CDP1802 and PIC18F47Q43
  Modifed by Kazuhiro Ouchi
*/

// CONFIG1
#pragma config FEXTOSC = OFF    // External Oscillator Selection (Oscillator not enabled)
#pragma config RSTOSC = HFINTOSC_64MHZ// Reset Oscillator Selection (HFINTOSC with HFFRQ = 64 MHz and CDIV = 1:1)

// CONFIG2
#pragma config CLKOUTEN = OFF   // Clock out Enable bit (CLKOUT function is disabled)
#pragma config PR1WAY = ON      // PRLOCKED One-Way Set Enable bit (PRLOCKED bit can be cleared and set only once)
#pragma config CSWEN = ON       // Clock Switch Enable bit (Writing to NOSC and NDIV is allowed)
#pragma config FCMEN = ON       // Fail-Safe Clock Monitor Enable bit (Fail-Safe Clock Monitor enabled)

// CONFIG3
#pragma config MCLRE = EXTMCLR  // MCLR Enable bit (If LVP = 0, MCLR pin is MCLR; If LVP = 1, RE3 pin function is MCLR )
#pragma config PWRTS = PWRT_OFF // Power-up timer selection bits (PWRT is disabled)
#pragma config MVECEN = ON      // Multi-vector enable bit (Multi-vector enabled, Vector table used for interrupts)
#pragma config IVT1WAY = ON     // IVTLOCK bit One-way set enable bit (IVTLOCKED bit can be cleared and set only once)
#pragma config LPBOREN = OFF    // Low Power BOR Enable bit (Low-Power BOR disabled)
#pragma config BOREN = SBORDIS  // Brown-out Reset Enable bits (Brown-out Reset enabled , SBOREN bit is ignored)

// CONFIG4
#pragma config BORV = VBOR_1P9  // Brown-out Reset Voltage Selection bits (Brown-out Reset Voltage (VBOR) set to 1.9V)
#pragma config ZCD = OFF        // ZCD Disable bit (ZCD module is disabled. ZCD can be enabled by setting the ZCDSEN bit of ZCDCON)
#pragma config PPS1WAY = OFF    // PPSLOCK bit One-Way Set Enable bit (PPSLOCKED bit can be set and cleared repeatedly (subject to the unlock sequence))
#pragma config STVREN = ON      // Stack Full/Underflow Reset Enable bit (Stack full/underflow will cause Reset)
#pragma config LVP = ON         // Low Voltage Programming Enable bit (Low voltage programming enabled. MCLR/VPP pin function is MCLR. MCLRE configuration bit is ignored)
#pragma config XINST = OFF      // Extended Instruction Set Enable bit (Extended Instruction Set and Indexed Addressing Mode disabled)

// CONFIG5
#pragma config WDTCPS = WDTCPS_31// WDT Period selection bits (Divider ratio 1:65536; software control of WDTPS)
#pragma config WDTE = OFF       // WDT operating mode (WDT Disabled; SWDTEN is ignored)

// CONFIG6
#pragma config WDTCWS = WDTCWS_7// WDT Window Select bits (window always open (100%); software control; keyed access not required)
#pragma config WDTCCS = SC      // WDT input clock selector (Software Control)

// CONFIG7
#pragma config BBSIZE = BBSIZE_512// Boot Block Size selection bits (Boot Block size is 512 words)
#pragma config BBEN = OFF       // Boot Block enable bit (Boot block disabled)
#pragma config SAFEN = OFF      // Storage Area Flash enable bit (SAF disabled)
#pragma config DEBUG = OFF      // Background Debugger (Background Debugger disabled)

// CONFIG8
#pragma config WRTB = OFF       // Boot Block Write Protection bit (Boot Block not Write protected)
#pragma config WRTC = OFF       // Configuration Register Write Protection bit (Configuration registers not Write protected)
#pragma config WRTD = OFF       // Data EEPROM Write Protection bit (Data EEPROM not Write protected)
#pragma config WRTSAF = OFF     // SAF Write protection bit (SAF not Write Protected)
#pragma config WRTAPP = OFF     // Application Block write protection bit (Application Block not write protected)

// CONFIG10
#pragma config CP = OFF         // PFM and Data EEPROM Code Protection bit (PFM and Data EEPROM code protection disabled)

// #pragma config statements should precede project file includes.
// Use project enums instead of #define for ON and OFF.

#include <xc.h>
#include <stdio.h>

//#define Z80_CLK 2500000UL // Z80 clock frequency(Max 16MHz)

//#define ROM_SIZE 0x4000 // ROM size 16K bytes
//#define RAM_SIZE 0x1000 // RAM size 4K bytes
//#define RAM_TOP 0x8000 // RAM start address

// CDP1802
//#define Z80_CLK 1800000UL // CDP1802 clock frequency(1.8MHz)
#define Z80_CLK   200000UL // CDP1802 clock frequency(0.2MHz)

// for Low address test ($0000-$00FF)
//#define ROM_SIZE 0x80 // ROM size 128 bytes
//#define RAM_SIZE 0x80 // RAM size 128 bytes
//#define RAM_TOP 0x80 // RAM start address

// for High Address (ROM $0000-$0400, RAM $8000-8FFF)
//#define ROM_SIZE 0x0030 // ROM size 256 bytes
#define ROM_SIZE 0x0400 // ROM size 1k bytes
#define RAM_SIZE 0x1000 // RAM size 4k bytes
#define RAM_TOP 0x8000 // RAM start address

#define UART_DREG 0xE000 // UART data register address
#define UART_CREG 0xE001 // UART control register address

#define _XTAL_FREQ 64000000UL

extern const unsigned char rom[]; // Equivalent to ROM, see end of this file
unsigned char ram[RAM_SIZE]; // Equivalent to RAM
static union {
    unsigned int w; // 16 bits Address
    struct {
        unsigned char l; // Address low 8 bits
        unsigned char h; // Address high 8 bits
    };
} address;
    

/*
// UART3 Transmit
void putch(char c) {
    while(!U3TXIF); // Wait or Tx interrupt flag set
    U3TXB = c; // Write data
}

// UART3 Recive
char getch(void) {
    while(!U3RXIF); // Wait for Rx interrupt flag set
    return U3RXB; // Read data
}
*/

//#define dff_reset() {G3POL = 1; G3POL = 0;}
#define db_setin() (TRISC = 0xff)
#define db_setout() (TRISC = 0x00)

// Never called, logically
void __interrupt(irq(default),base(8)) Default_ISR(){}

/**
   IOCAF1 Interrupt Service Routine TPB(RA1) Rising edge
 */
// Called at COSMAC TPB(RA1) Rising edge
void IOCAF1_ISR(void) {
    IOCAFbits.IOCAF1 = 0;
    //address.h = 0; // Read address high (256byte only)
    address.l = PORTB; // Read address low
    
    if(!RA5) { // COSMAC memory read cycle (MRD active)
        db_setout(); // Set data bus as output
        if(address.w < ROM_SIZE){ // ROM area
            LATC = rom[address.w]; // Out ROM data
        } else if((address.w >= RAM_TOP) && (address.w < (RAM_TOP + RAM_SIZE))){ // RAM area
            LATC = ram[address.w - RAM_TOP]; // RAM data
        //} else if(address.w == UART_CREG){ // UART control register
        //    LATC = PIR9; // U3 flag
        //} else if(address.w == UART_DREG){ // UART data register
        //    LATC = U3RXB; // U3 RX buffer
        } else { // Out of memory
            LATC = 0xff; // Invalid data
        }
    } else { // COSMAC memory write cycle (MWR active)
        //if(RE0) while(RE0);
        if(!RE0) {
            if((address.w >= RAM_TOP) && (address.w < (RAM_TOP + RAM_SIZE))){ // RAM area
                ram[address.w - RAM_TOP] = PORTC; // Write into RAM
            //} else if(address.w == UART_DREG) { // UART data register
            //    U3TXB = PORTC; // Write into U3 TX buffer
            }
        }
    }
}

/**
   IOCAF2 Interrupt Service Routine
*/
// Called at COSMAC TPA(RA2) Falling edge
void IOCAF2_ISR(void) {
    IOCAFbits.IOCAF2 = 0;
    address.h = PORTB;  // Read address high
}

void __interrupt(irq(IOC),base(8)) PIN_MANAGER_IOC()
{   
	// interrupt on change for pin IOCAF1
    if(IOCAFbits.IOCAF1 == 1)
    {
        IOCAF1_ISR();  
    }	
	// interrupt on change for pin IOCAF2
    if(IOCAFbits.IOCAF2 == 1)
    {
        IOCAF2_ISR();  
    }	
}

#ifdef false

// Called at COSMAC TPB falling edge (PIC18F47Q43 issues WAIT)
void __interrupt(irq(CLC1),base(8)) CLC1_ISR(){
    CLC1IF = 0; // Clear interrupt flag
    
    //address.h = 0; // Read address high (256byte only)
    address.l = PORTB; // Read address low
    
    if(!RA5) { // COSMAC memory read cycle (MRD active)
        db_setout(); // Set data bus as output
        if(address.w < ROM_SIZE){ // ROM area
            LATC = rom[address.w]; // Out ROM data
        } else if((address.w >= RAM_TOP) && (address.w < (RAM_TOP + RAM_SIZE))){ // RAM area
            LATC = ram[address.w - RAM_TOP]; // RAM data
        //} else if(address.w == UART_CREG){ // UART control register
        //    LATC = PIR9; // U3 flag
        //} else if(address.w == UART_DREG){ // UART data register
        //    LATC = U3RXB; // U3 RX buffer
        } else { // Out of memory
            LATC = 0xff; // Invalid data
        }
    } else { // COSMAC memory write cycle (MRD inactive)
        //if(RE0) while(RE0);
        if((address.w >= RAM_TOP) && (address.w < (RAM_TOP + RAM_SIZE))){ // RAM area
            ram[address.w - RAM_TOP] = PORTC; // Write into RAM
            //} else if(address.w == UART_DREG) { // UART data register
            //    U3TXB = PORTC; // Write into U3 TX buffer
        }
    }
    dff_reset(); // WAIT inactive
}

// Called at COSMAC TPA falling edge (PIC18F47Q43 issues WAIT)
void __interrupt(irq(CLC2),base(8)) CLC2_ISR()
{
    CLC2IF = 0;         // Clear the CLC interrupt flag
    address.h = PORTB;  // Read address high
}

#endif

//  Called at COSMAC TPB(RA1) Falling edge
void __interrupt(irq(INT0),base(8)) INT0_ISR(){
    INT0IF = 0; // Clear interrupt flag
    db_setin(); // Set data bus as input
}

// main routine
void main(void) {
    // System initialize
    OSCFRQ = 0x08; // 64MHz internal OSC

    // Address bus A15-A8 pin (RD0-RD7) --- Unused
    ANSELD = 0x00; // Disable analog function
    WPUD = 0xff; // Week pull up
    TRISD = 0xff; // Set as input

    // Address bus A7-A0 pin (RB0-RB7)
    ANSELB = 0x00; // Disable analog function
    WPUB = 0xff; // Week pull up
    TRISB = 0xff; // Set as input

    // Data bus D7-D0 pin (RC0-RC7)
    ANSELC = 0x00; // Disable analog function
    WPUC = 0xff; // Week pull up
    TRISC = 0xff; // Set as input(default)

    // MWR input pin (RE0)
    ANSELE0 = 0; // Disable analog function
    WPUE0 = 1; // Week pull up
    TRISE0 = 1; // Set as input

    // RESET output pin (RE1)
    ANSELE1 = 0; // Disable analog function
    LATE1 = 0; // Reset
    TRISE1 = 0; // Set as output

    // INT output pin (RE2) --- Unused
    //ANSELE2 = 0; // Disable analog function
    //LATE2 = 1; // No interrupt request
    //TRISE2 = 0; // Set as output

    // MRD input pin (RA5)
    ANSELA5 = 0; // Disable analog function
    WPUA5 = 1; // Week pull up
    TRISA5 = 1; // Set as intput

    // clock(RA3) by NCO FDC mode
    RA3PPS = 0x3f; // RA3 asign NCO1
    ANSELA3 = 0; // Disable analog function
    TRISA3 = 0; // PWM output pin
    NCO1INCU = (unsigned char)((Z80_CLK*2/61/65536) & 0xff);
    NCO1INCH = (unsigned char)((Z80_CLK*2/61/256) & 0xff);
    NCO1INCL = (unsigned char)((Z80_CLK*2/61) & 0xff);
    NCO1CLK = 0x00; // Clock source Fosc
    NCO1PFM = 0;  // FDC mode
    NCO1OUT = 1;  // NCO output enable
    NCO1EN = 1;   // NCO enable

    // UART3 initialize
    //U3BRG = 416; // 9600bps @ 64MHz
    //U3RXEN = 1; // Receiver enable
    //U3TXEN = 1; // Transmitter enable

    // UART3 Receiver
    //ANSELA7 = 0; // Disable analog function
    //TRISA7 = 1; // RX set as input
    //U3RXPPS = 0x07; //RA7->UART3:RX3;

    // UART3 Transmitter
    //ANSELA6 = 0; // Disable analog function
    //LATA6 = 1; // Default level
    //TRISA6 = 0; // TX set as output
    //RA6PPS = 0x26;  //RA6->UART3:TX3;

    //U3ON = 1; // Serial port enable
    
    
    // TPB(RA1) CLC1 input pin
    ANSELA1 = 0; // Disable analog function
    WPUA1 = 1; // Week pull up
    TRISA1 = 1; // Set as input
    //CLCIN0PPS = 0x1; //RA1->CLC1:CLCIN0;

    // TPA(RA2) CLC2 input pin
    ANSELA2 = 0; // Disable analog function
    WPUA2 = 1; // Week pull up
    TRISA2 = 1; // Set as input
    //CLCIN1PPS = 0x2; //RA2->CLC1:CLCIN1;

    // RA4 CLC1 output pin --- debug
    //ANSELA4 = 0; // Disable analog function
    //LATA4 = 1; // Default level
    //TRISA4 = 0; // Set as output
    //RA4PPS = 0x01;  //RA4->CLC1:CLC1;

    // RA0 CLC2 output pin --- debug   
    //ANSELA0 = 0; // Disable analog function
    //LATA0 = 1; // Default level
    //TRISA0 = 0; // Set as output
    //RA0PPS = 0x02;  //RA0->CLC2:CLC2;
  
#ifdef false
    //CLC1 configuration
    CLCSELECT = 0x0; // CLC1 instance  
    CLCnPOL = 0x82; // LCG2POL inverted, LCPOL inverted

    // CLC data inputs select
    CLCnSEL0 = 0x2a;  // D-FF CLK assign NC01
    CLCnSEL1 = 0; // D-FF D assign CLCIN0PPS(RA1) 
    CLCnSEL2 = 127; // D-FF S assign none
    CLCnSEL3 = 127; // D-FF R assign none

    // CLCn gates logic select
    CLCnGLS0 = 0x1; // Connect LCG1D1N 
    CLCnGLS1 = 0x4; // Connect LCG2D2N
    CLCnGLS2 = 0x0; // Connect none
    CLCnGLS3 = 0x0; // Connect none

    CLCDATA = 0x0; // Clear all CLC outs
    CLCnCON = 0x8c; // Select D-FF, falling edge inturrupt
#endif

    
    // INTERRUPT_Initialize
    //
    // Vectored Interrupt Controller setting sequence
    INTCON0bits.IPEN = 1; // Interrupt priority enable

    IVTLOCK = 0x55;
    IVTLOCK = 0xAA;
    IVTLOCKbits.IVTLOCKED = 0x00; // Unlock IVT

    IVTBASEU = 0;
    IVTBASEH = 0;
    IVTBASEL = 8; // Default VIT base address

    IVTLOCK = 0x55;
    IVTLOCK = 0xAA;
    IVTLOCKbits.IVTLOCKED = 0x01; // Lock IVT

    // Assign peripheral interrupt priority vectors
    IPR0bits.IOCIP = 1;

    /**
    IOCx registers 
    */
    //interrupt on change for group IOCAF - flag COSMAC TPB(RA1)
    IOCAFbits.IOCAF1 = 0;
    //interrupt on change for group IOCAF - flag COSMAC TPA(RA2)
    IOCAFbits.IOCAF2 = 0;
    //interrupt on change for group IOCAN - negative
    IOCANbits.IOCAN1 = 0;
    //interrupt on change for group IOCAN - negative COSMAC TPA(RA2) Falling edge
    IOCANbits.IOCAN2 = 1;
    //interrupt on change for group IOCAP - positive COSMAC TPB(RA1) Rising edge
    IOCAPbits.IOCAP1 = 1;
    //interrupt on change for group IOCAP - positive
    IOCAPbits.IOCAP2 = 0;
 
    // Enable IOCI interrupt 
    PIE0bits.IOCIE = 1; 


#ifdef false
    // CLC VI enable
    CLC1IF = 0; // Clear the CLC interrupt flag
    CLC1IE = 1; // Enabling CLC1 interrupt
    
    // Assign peripheral interrupt priority vectors
    IPR6bits.CLC2IP = 1;
    IPR0bits.CLC1IP = 1;
  
    // Set the CLC2 to the options selected in the User Interface
     
    CLCSELECT = 0x01;   // SLCT 1;   
    CLCnPOL = 0x83;     // G1POL not_inverted; G2POL inverted; G3POL not_inverted; G4POL not_inverted; POL inverted;
    CLCnSEL0 = 0x2a;    // D1S NCO1_OUT; 
    CLCnSEL1 = 0x01;    // D2S CLCIN1 (NC01);
    CLCnSEL2 = 0x00;    // D2S CLCIN1 (CLCIN1PPS);   
    CLCnSEL3 = 0x00;    // D3S CLCIN0 (CLCIN0PPS);
    CLCnGLS0 = 0x01;    // G1D3N disabled; G1D2N disabled; G1D4N disabled; G1D1T disabled; G1D3T disabled; G1D2T disabled; G1D4T disabled; G1D1N enabled;  
    CLCnGLS1 = 0x04;    // G2D2N enabled; G2D1N disabled; G2D4N disabled; G2D3N disabled; G2D2T disabled; G2D1T disabled; G2D4T disabled; G2D3T disabled; 
    CLCnGLS2 = 0x00;    // G3D1N disabled; G3D2N disabled; G3D3N disabled; G3D4N disabled; G3D1T disabled; G3D2T disabled; G3D3T disabled; G3D4T disabled; 
    CLCnGLS3 = 0x00;    // G4D1N disabled; G4D2N disabled; G4D3N disabled; G4D4N disabled; G4D1T disabled; G4D2T disabled; G4D3T disabled; G4D4N disabled; 
    CLCDATA = 0x00;     // CLC2OUT 0; 
    CLCnCON = 0x8C;     // EN enabled; INTN enabled; INTP disabled; MODE 1-input D flip-flop with S and R;

    CLC2IF = 0; // Clear the CLC interrupt flag
    CLC2IE = 1; // Enabling CLC2 interrupt.

#endif

    // INT0 VI enable
    // COSMAC TPB(RA1) Falling edge
    INT0PPS = 0x1; //RA1->INTERRUPT MANAGER:INT0;
    INT0EDG = 0; // 0: Falling edge 1: Rising edge
    INT0IE = 1;
   
    // COSMAC start
    GIE = 1; // Global interrupt enable
    LATE1 = 1; // Release reset COSMAC ~CLEAR(RE1)
    
    while(1); // All things come to those who wait
}

// blink program 1
//00  7B               1->Q
//01  7A               0->Q
//02  30 00            00->R(P).0

// Counter program 2 (Low RAM $0081 R/W)
//0000 F8 81             8 (   2) START   LDI     #IOR    ;D <- $81  $0081
//0002 A3                9 (   2)         PLO     3       ;R(3).0 <- D
//0003 E3               10 (   2)         SEX     3       ;X <- 3
//0004 84               11 (   2) LOOP1   GLO     4       ;D <- R(4).0
//0005 53               12 (   2)         STR     3       ;M(R(3)) <- D
//0006 61               13 (   2)         OUT     1       ;BUS <- M(R(3)); R(3)++
//0007 23               14 (   2)         DEC     3       ;R(3)--
//0008 14               15 (   2)         INC     4       ;R(4)++
//0009 30 04            16 (   2)         BR      LOOP1   ;Branch to LOOP1

// Counter program 3  (High RAM $8008 R/W)
//0000 F8 80             8 (   2) START   LDI     /RAM    ;D <- $80  $8007
//0002 B3                9 (   2)         PHI     3       ;R(3).1 <- D
//0003 F8 08            10 (   2)         LDI     #RAM    ;D <- $07
//0005 A3               11 (   2)         PLO     3       ;R(3).0 <- D
//0006 E3               13 (   2)         SEX     3       ;X <- 3
//0007 84               14 (   2) LOOP1   GLO     4       ;D <- R(4).0
//0008 53               15 (   2)         STR     3       ;M(R(3)) <- D
//0009 61               16 (   2)         OUT     1       ;BUS <- M(R(3)); R(3)++
//000A 23               17 (   2)         DEC     3       ;R(3)--
//000B 14               18 (   2)         INC     4       ;R(4)++
//000C 30 07            19 (   2)         BR      LOOP1   ;Branch to LOOP1

// memory move program 4
// $0000-$0030 -> $8008-$8038 + OUT 1
//0000-                  7        SOURCE  .EQ     $0000
//0070-                  9        MAXADD  .EQ     $0030
//0080-                  8        DESTIN  .EQ     $8008
//00F0-                 10        MAXDUMP .EQ     $8039
//0000-                 13        PROGPC  .EQ     0
//
//0000-F8 00            33 (   2) START:  LDI     /BEG
//0002-B9               34 (   2)         PHI     R9
//0003-F8 07            35 (   2)         LDI     #BEG
//0005-A9               36 (   2)         PLO     R9
//0006-D9               37 (   2)         SEP     R9
//0007-                 38
//0007-F8 00            39 (   2) BEG:    LDI     /SOURCE
//0009-BA               40 (   2)         PHI     RA
//000A-F8 00            41 (   2)         LDI     #SOURCE
//000C-AA               42 (   2)         PLO     RA
//000D-                 43
//000D-F8 80            44 (   2)         LDI     /DESTIN
//000F-BB               45 (   2)         PHI     RB
//0010-F8 08            46 (   2)         LDI     #DESTIN
//0012-AB               47 (   2)         PLO     RB
//0013-                 48
//0013-4A               49 (   2) REPEAT: LDA     RA
//0014-5B               50 (   2)         STR     RB
//0015-1B               51 (   2)         INC     RB
//0016-8A               52 (   2)         GLO     RA
//0017-FB 31            53 (   2)         XRI     #MAXADD+1
//0019-3A 13            54 (   2)         BNZ     REPEAT
//001B-                 55
//001B-F8 80            56 (   2) DUMP:   LDI     /DESTIN
//001D-BB               57 (   2)         PHI     RB
//001E-F8 08            58 (   2)         LDI     #DESTIN
//0020-AB               59 (   2)         PLO     RB
//0021-EB               60 (   2)         SEX     RB
//0022-61               61 (   2) REPEAT2: OUT    1
//0023-8B               62 (   2)         GLO     RB
//0024-FB 39            63 (   2)         XRI     #MAXDUMP+1
//0026-3A 22            64 (   2)         BNZ     REPEAT2
//0028-                 65
//0028-                 66
//0028-30 28            67 (   2) ENDLOOP: BR ENDLOOP

const unsigned char rom[ROM_SIZE] = {
#ifdef false
    // Program 1: Blink
    0x7b, 0x7a, 0x30, 0x00, 0xff, 0xff, 0xff, 0xff, // 0000

    // Program 2: Counter2 (Low RAM $0081 R/W)
    0xf8, 0x81, 0xa3, 0xe3, 0x84, 0x53, 0x61, 0x23, // 0000
    0x14, 0x30, 0x04, 0xff, 0xff, 0xff, 0xff, 0xff,
    0xff, 0xff, 0xff, 0xff, 0xff, 0xff, 0xff, 0xff, // 0010
    0xff, 0xff, 0xff, 0xff, 0xff, 0xff, 0xff, 0xff
            
    // Program 3: Counter3 (High RAM $8008 R/W)
    0xf8, 0x80, 0xb3, 0xf8, 0x08, 0xa3, 0xe3, 0x84, // 0000
    0x53, 0x61, 0x23, 0x14, 0x30, 0x07, 0xff, 0xff,
    0xff, 0xff, 0xff, 0xff, 0xff, 0xff, 0xff, 0xff, // 0010
    0xff, 0xff, 0xff, 0xff, 0xff, 0xff, 0xff, 0xff,
    0xff, 0xff, 0xff, 0xff, 0xff, 0xff, 0xff, 0xff, // 0020
    0xff, 0xff, 0xff, 0xff, 0xff, 0xff, 0xff, 0xff
            
    // Program 4: memory move and dump $0000 -> $8008 $30byte
    0xF8, 0x00, 0xB9, 0xF8, 0x07, 0xA9, 0xD9, 0xF8, // 0000
    0x00, 0xBA, 0xF8, 0x00, 0xAA, 0xF8, 0x80, 0xBB,
    0xF8, 0x08, 0xAB, 0x4A, 0x5B, 0x1B, 0x8A, 0xFB, // 0010
    0x31, 0x3A, 0x13, 0xF8, 0x80, 0xBB, 0xF8, 0x08,
    0xAB, 0xEB, 0x61, 0x8B, 0xFB, 0x39, 0x3A, 0x22, // 0020
    0x30, 0x28, 0xff, 0xff, 0xff, 0xff, 0xff, 0xff

    // Program 5: Save register (Save area $8000-$801F)
    0xF8, 0x00, 0xB0, 0xF8, 0x80, 0xB1, 0xF8, 0x1E, // 0000
    0xA1, 0xF8, 0xA0, 0xB4, 0xE1, 0xF8, 0xD0, 0x51,
    0xF3, 0x3A, 0x28, 0x21, 0x94, 0xFC, 0x70, 0x33, // 0010
    0x1B, 0xFC, 0x21, 0xFC, 0x7F, 0xB4, 0x51, 0xF3,
    0x3A, 0x28, 0xD1, 0x51, 0x21, 0x21, 0x30, 0x0D, // 0020
    0x30, 0x28, 0xff, 0xff, 0xff, 0xff, 0xff, 0xff
#endif
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

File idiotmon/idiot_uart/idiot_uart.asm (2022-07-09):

        .LF     idiot_uart
        .TF     idiot_uart.bin,BIN

;-------------------------------------------------------------;
; IDIOT/4 MONITOR FOR THE 1802	 WRITTEN: 6/23/82 BY LEE HART ;
; COPYRIGHT 1982-85 BY TMSI	LAST MOD: 3/28/86 BY LEE HART ;
;							      ;
; This program may be used for any noncommercial use free of  ;
; charge. Contact information: Lee A. Hart, 814 8th Ave N,    ;
; Sartell MN 56377, email <leeahart@earthlink.net>	      ;
;-------------------------------------------------------------;
;
;fixes by Herb Johnson HRJ April 2010, Jan 2014
; changed "DC" to "DB"
; ORGed to 8000H for 1802 Membership Card
; changed other ORG [value] to RESET+[value]
;operating notes
;  EF4 is serial in (BN4), Q is serial out 
;  (M/S card uses EF4 for IN toggle, change to EF3 - BN3&B3 instructions) 
;  OUT 7 "turn reader on" bit 7 "off" bit 6
;
;fixes for Feb 2014 - RS-232 interface inverts serial input and output 
;so EF3 and Q need to be active LOW
;will make IF EFHI....ELSE ....ENDI statements
; and      IF QHI....ELSE...ENDI
EFHI	.EQ	0	; 0=active low EF for serial
QHI	.EQ	0	; 0=active low Q for serial
;
; For EMU1802-mini using PIC18 UART
; by Kazuhiro Ouchi July 2022
;
; register equivalents for A18
R0		.EQ	0
R1		.EQ	1
R2		.EQ	2
R3		.EQ	3
R4		.EQ	4
R5		.EQ	5
R6		.EQ	6
R7		.EQ	7
R8		.EQ	8
R9		.EQ	9
RA		.EQ	10
RB		.EQ	11
RC		.EQ	12
RD		.EQ	13
RE		.EQ	14
RF		.EQ	15
;
;
; REGISTER ASSIGNMENTS:
;
;		1 - INTERRUPT PROGRAM COUNTER (FOR BREAKPOINTS)
;		2 - STACK POINTER
;		3 - NORMAL PROGRAM COUNTER
;		4 - MONITOR: RAM PAGE0 POINTER
;		    BASIC:   SCRT "CALL" PC
;		5 - MONITOR: MAIN PC
;		    BASIC:   SCRT "RETURN" PC
;		6 - UART REGISTER ADDRESS
;		8 - MONITOR: ?M VS. !M SWITCH
;	       10 - MONITOR: MEMORY POINTER
DELAY	.EQ    12 ; PC FOR DELAY SUBROUTINE
HEXX	.EQ    13 ; MONITOR: HEX ADDRESS ACCUMULATOR
BAUD	.EQ    14 ; RE.1=BAUD RATE CONSTANT
;		    RE.0=USED FOR READ, TYPE
ASCII	.EQ    15 ; RF.1=ASCII I/O CHARACTER
;		    RF.0=USED FOR READ, TYPE
;
; .EQATES
;
TYPA	.EQ	0D3H		; TYPE CHARACTER MACRO
;
; UART
;
UARTDR	.EQ	0E000H		;DATA REG
UARTCR	.EQ	0E001H		;CONTROL REG
;
	.CR	1802
;	.OR	8000H		;HRJ for Membership Card
	.OR	0000H		;HRJ for Membership Card
RESET	DIS			; DISABLE INTERRUPTS
	.DB	0
FINDRAM LDI	0FFH		; FIND RAM, STARTING AT FFFF
	PHI	R4
TRYAGAIN LDI	0FFH		; REPEAT...
	PLO	R4		; - TEST TOP BYTE ON PAGE
	STR	R4		; - STORE 'FF'
	LDN	R4		;   READ IT BACK,
	XRI	0FFH		;   COMPARE
	LSNZ			; - IF OK, STORE ALL 0'S,
	STR	R4		;   READ BACK,
	LDN	R4		;   COMPARE
	BZ	RAMFOUND	; - IF OK, THEN RAM FOUND
	GHI	R4		; - IF NO MORE PAGES TO TEST,
	BZ	NORAM		;      THEN GO TO NORAM
	PLO	R4		;      ELSE DEC. PAGE NUMBER
	DEC	R4
	GLO	R4
	PHI	R4		; ...UNTIL DONE
	BR	TRYAGAIN
RAMFOUND LDI	0DFH		; RAM FOUND:
	PLO	R4		; SAVE CPU REGISTERS
	SEX	R4
;
; SAVE REGISTERS:  SAVES A COPY OF ALL CPU REGISTERS & I/O BITS
;	IN RAM. MUST BE ENTERED WITH P=R0 OR R1, X=R4.	SAVES
;	ALL REGISTERS CORRECTLY EXCEPT P, X, D, R(P), AND R4.
;
SAVER	GLO	RF		; SAVE REGISTERS R0-RF IN RAM
	STXD
	GHI	RF		; RF 1ST, R0 LAST,
	STXD			; WITH HI BYTE IN LOWER ADDRESS
	GLO	RE
	STXD
	GHI	RE
	STXD			; THE REGISTERS BEING USED FOR PROGRAM
	GLO	RD		; COUNTER AND RAM POINTER ARE CHANGING
	STXD			; DURING EXECUTION, SO THEIR STORED VALUES
	GHI	RD		; WILL BE FIXED LATER.
	STXD
	GLO	RC
	STXD
	GHI	RC
	STXD
	GLO	RB
	STXD
	GHI	RB
	STXD
	GLO	RA
	STXD
	GHI	RA
	STXD
	GLO	R9
	STXD
	GHI	R9
	STXD
	GLO	R8
	STXD
	GHI	R8
	STXD
	GLO	R7
	STXD
	GHI	R7
	STXD
	GLO	R6
	STXD
	GHI	R6
	STXD
	GLO	R5
	STXD
	GHI	R5
	STXD
	STXD			; DON'T BOTHER TO SAVE R4 (SAVES 2 BYTES)
	STXD
	GLO	R3
	STXD
	GHI	R3
	STXD
	GLO	R2
	STXD
	GHI	R2
	STXD
	GLO	R1
	STXD
	GHI	R1
	STXD
	GLO	R0
	STXD
	GHI	R0
	STXD
	LDI	0		; LOAD 0 (& SAVE A COPY FOR LATER)
	PHI	R3
	BN4	$+4		; PACK STATUS OF EF4 & EF3 INTO 1 BYTE
	ORI	004H		; AND PUSH INTO RAM
	BN3	$+4		;   X4 - EF4 ACTIVE
	ORI	030H		;   3X - EF3 ACTIVE
	STXD
	GHI	R3		; PACK STATUS OF EF2 & EF1 INTO 1 BYTE
	BN2	$+4		; AND PUSH INTO RAM
	ORI	002H		;   X2 - EF2 ACTIVE
	BN1	$+4		;   1X - EF1 ACTIVE
	ORI	010H
	STXD
	GHI	R3		; PUSH STATUS OF Q INTO RAM
	LSNQ			;   1 - Q ACTIVE
	ORI	1		;   0 - Q INACTIVE
	STXD
	LDI	1		; PUSH STATUS OF IE INTO RAM
	LSIE			;   1 - ENABLED
	LDI	0		;   0 - DISABLED
	STXD
	GHI	R3		; PUSH D(=0) TO RAM (DUMMY VALUE)
	STXD
	ADCI	0		; PUSH DF INTO RAM
	STXD
	SAV			; PUSH T INTO RAM
	DEC	R4
	LDI	#IFINT	; IF CALLED VIA INTERRUPT, RETURN
	PLO	R1
	GHI	R0		; ELSE CALLED VIA RESET,
	PHI	R1		;      SET RP=R1
	LDI	#$+4
	PLO	R1
	SEP	R1
	LDI	0		; PUSH STATUS=0
	STR	R4
;
CONTINIT LDI	#CHANGE	; COPY CODE THAT CHANGES TO THE DESIRED PC
	PLO	R5		; FOR A $R COMMAND. THE CODE GOES TO 35 BYTES
	GHI	R1		; BEFORE "SAVEREG" MEMORY
	ADI	3
	PHI	R5
	LDI	0A0H
	PLO	R4
	LDI	24
	PLO	R3
INITLOOP LDA	R5		; LOOP AND MOVE THE BYTES
	STR	R4
	INC	R4
	DEC	R3		; R4 WILL END UP POINTING TO XXB8
	GLO	R3
	BNZ	INITLOOP
	GHI	R4		; INITIALIZE R2 (STACK POINTER)
	PHI	R2
	LDI	0C3H		; CORRECT STORED VALUE OF R1
	PLO	R4
	LDI	#INTERUPT
	STXD
	GHI	R1
	STXD
	GHI	R1		; LOAD R5 WITH ADDRESS OF "ENTRY"
	ADI	1
	PHI	R5
	LDI	#ENTRY
	PLO	R5
	LDI	0FEH		; POINT R3 TO TIMALC
	PLO	R3
	GHI	R1
	PHI	R3		; CALL TIMALC; IT RETURNS WITH "SEP R5",
;	SEP	R3		; SO IT WILL RETURN TO "ENTRY"
	LDI	0E0H		; R6 <- UART REGISTER ADDRESS $E000
	PHI	R6
	LDI	0
	PLO	R6
	SEP	R5		; Straight to Monitor
;
; INTERUPT:  INTERRUPT HANDLER FOR IDIOT MONITOR. HARDWARE INTERRUPT
;	SAVES ALL REGISTERS EXCEPT T CORRECTLY. A SOFTWARE INTERRUPT
;	(D1=SEP R1) SAVES ALL BUT P AND X CORRECTLY. R2 MUST POINT TO
;	A STACK WITH AT LEAST 4 FREE BYTES TO SAVE D AND R4 CORRECTLY.
;
INTERUPT SEX	R2		; ENTRY: OLD P AND X DESTROYED
	DEC	R2		; DEC. STACK POINTER TO FREE LOCATION
	STXD			; PUSH D
	GHI	R4		; PUSH R4
	STXD
	GLO	R4
	STR	R2
	SEX	R4		; SET X=R4 AND GO TO SAVE REGISTERS
	BR	FINDRAM
IFINT	LDI	010H		; RETURN HERE:
	STXD			; PUSH STATUS=10
	LDI	0C9H		; CORRECT STORED CONTENTS OF R4
	PLO	R4
	LDA	R2
	STXD
	LDA	R2
	STXD
	LDI	0BBH		; CORRECT STORED CONTENTS OF D
	PLO	R4
	LDA	R2
	STR	R4
	LDI	0C5H		; CORRECT STORED VALUE OF STACK POINTER
	PLO	R4		; TO ACTUAL VALUE AT TIME OF INTERRUPT
	GLO	R2
	STXD
	GHI	R2
	STXD
	BR	CONTINIT	; GO CONTINUE INITIALIZATION
;
NORAM	GHI	R0		; NO RAM: CAN'T SAVE REGISTERS
	ADI	1
	PHI	R3
	LDI	#ENTRY	; CHANGE PROGRAM COUNTER TO R3
	PLO	R3
	SEX	R2		; STACK POINTER TO R2
	SEP	R3		; GO TO IDIOT/2
;
; READ: READS A SERIAL CHARACTER VIA EF4 AND RETURNS WITH ITS ASCII CODE IN
;	ASCII.1 AND D (BUT D WILL BE LOST IF SCRT CALL & RETURN IS USED).
;	EXPECTS P=3; ALTERS DF, ASCII, & BAUD.0; AND RETURNS WITH SEP R5. 
;
; TTYRED:  SAME AS "READ", BUT FIRST DOES AN "OUT 7" X'80' TO TURN ON 
;	A SERIAL INPUT DEVICE SUCH AS A TAPE RECORDER. ONCE A CHARACTER HAS
;	STARTED, AN "OUT 7" X'40' IS USED TO TURN IT OFF AGAIN.
;
; READAH:  SAME AS "READ", BUT IF A HEX CHARACTER (0-9, A-F), IT IS ALSO 
;	SHIFTED INTO THE LOW 4 BITS OF "HEXX" & DF=1 IS RETURNED; IF NOT
;	HEX, RETURNS DF=0, "READAH" USES P=R3, ALTERS D, DF, RF, RE.0, &
;	RETURNS WITH A "SEP R5" AND R3 POINTING TO "READAH" ENTRY POINT.
;
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

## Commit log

2022-06-05 Added schematic of EMU1802.
2022-06-05 Added sample programs for IDIOT monitor
2022-06-19 Added EMU1802-mini Schematic
2022-06-20 Added BOM for EMU1802-mini
2022-06-20 Updated BOM
2022-06-23 Added KiCad 6.0 files
    [emu1802.kicad_sch, emu1802_mini.kicad_pcb, emu1802_mini.kicad_sch]
2022-06-24 Updated Schematic Rev. 1.0
2022-06-25 Updated BOM Rev. 1.0
2022-07-03 Added echoback for uart
2022-07-04 Added HelloWorld and Echo back for PIC UART
2022-07-05 Added uart sample program for idiot monitor
2022-07-09 Bugfix IDIOT Using UART of PIC
    [idiot_uart.asm, main.c]
2022-07-12 Updated emu1802-mini PCB Rev.1.0
    [emu1802_mini.kicad_pcb, emu1802_mini.kicad_sch]
